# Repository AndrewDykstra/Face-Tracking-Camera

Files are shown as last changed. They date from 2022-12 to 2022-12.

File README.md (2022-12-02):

# Face-Tracking-Camera
This is a project I developed in my Engineering Honors class in high school which utilized an Arduino Rev3 and micro servos functioning as a pan-tilt to develop a face tracking camera.

I worked with the open source real-time computer vision library OpenCV for this project which is in C++, but I primarily coded in python. I developed the entire project at a cost of $45.76 which is significantly cheaper than alternative face tracking cameras on the market.

To physically encase the project, I had an iPhone box that I used an exacto knife to cut slits in to fit the wires through in order to connect to the webcam mounted on two micro servos. The two micro servos act as a pan-tilt so the camera can move accordingly when it indentifies a face to keep the face centered in the video. Inside of the iPhone box is the Arduino Rev3 and the breadboard that connects the Arduino to the micro servos. The last hole on the box is to connect the Arduino to my laptop where the code will be run to process the video feed from the webcam along with providing the Arduino with power.

This was one of my first larger projects where I properly documented my work in an engineering notebook and went through a proper design cycle of identifying the problem, researching solutions, identifying specifications, and prototyping. My engineering notebook is in the form of a pdf in this repository if you're interested in seeing more in depth data on my project along with regular progress updates.

The initial planning, designing, development, and any related information can be found in my engineering notebook. It also contains information on any bugs and difficulties along the way and I how I went about solving them.

Here are some pictures of what the final product looked like:

Outside look of the device
Inside look of the device
Facial recognition working

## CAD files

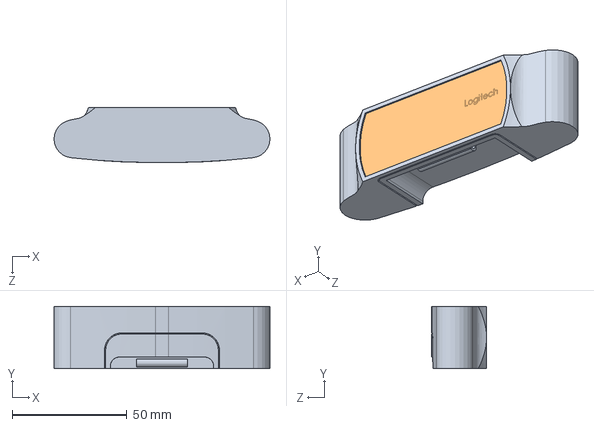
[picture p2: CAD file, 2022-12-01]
3D Model Parts and Assembly/LogitechC920Montaj.SLDASM
94.0 x 27.0 x 24.0 mm
Logitech_C920
Logitech_C920Glass

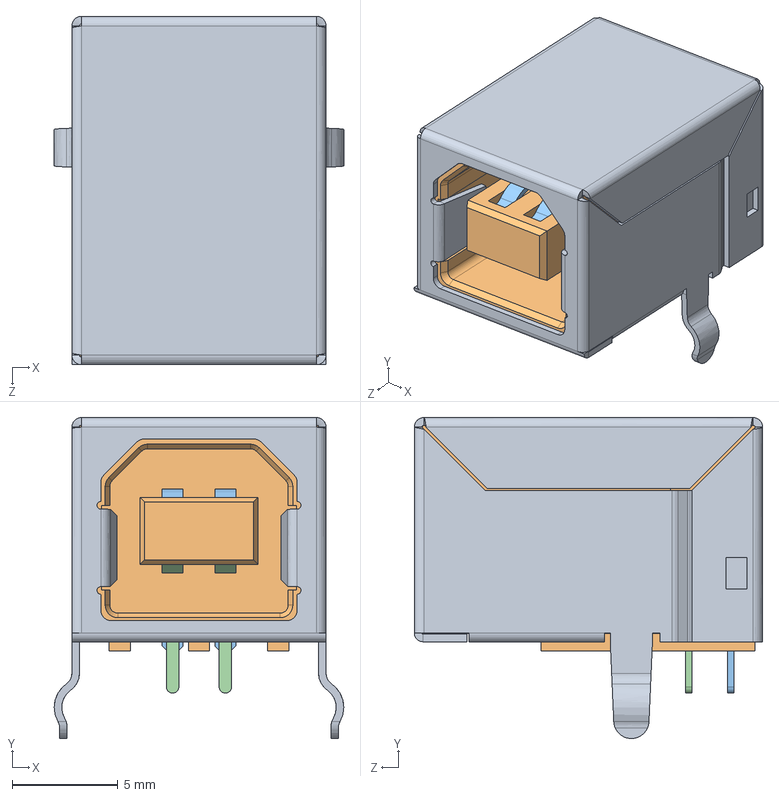
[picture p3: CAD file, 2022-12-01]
3D Model Parts and Assembly/ArduinoUno/USB type b.SLDPRT.SLDASM
13.7 x 15.2 x 16.5 mm
USB SHELL
USB core
usb top contact x 2
usb btm contact x 2

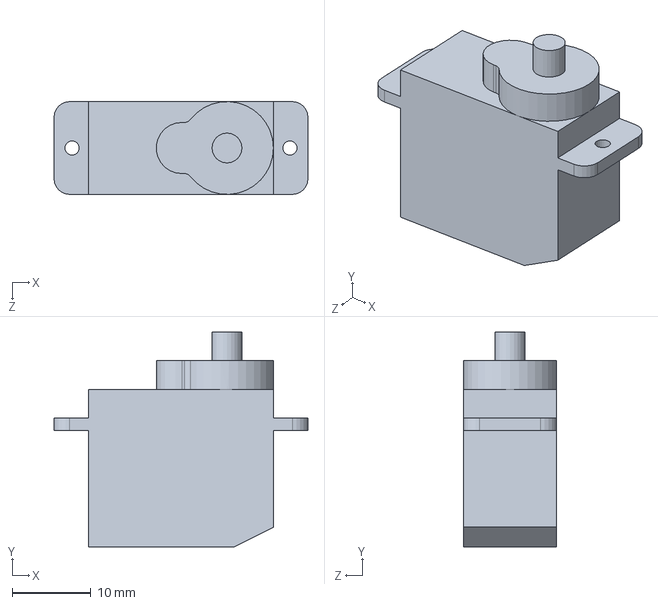
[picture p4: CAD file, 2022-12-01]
3D Model Parts and Assembly/servo_emax_9g_main_body.SLDPRT
32.3 x 27.3 x 11.8 mm

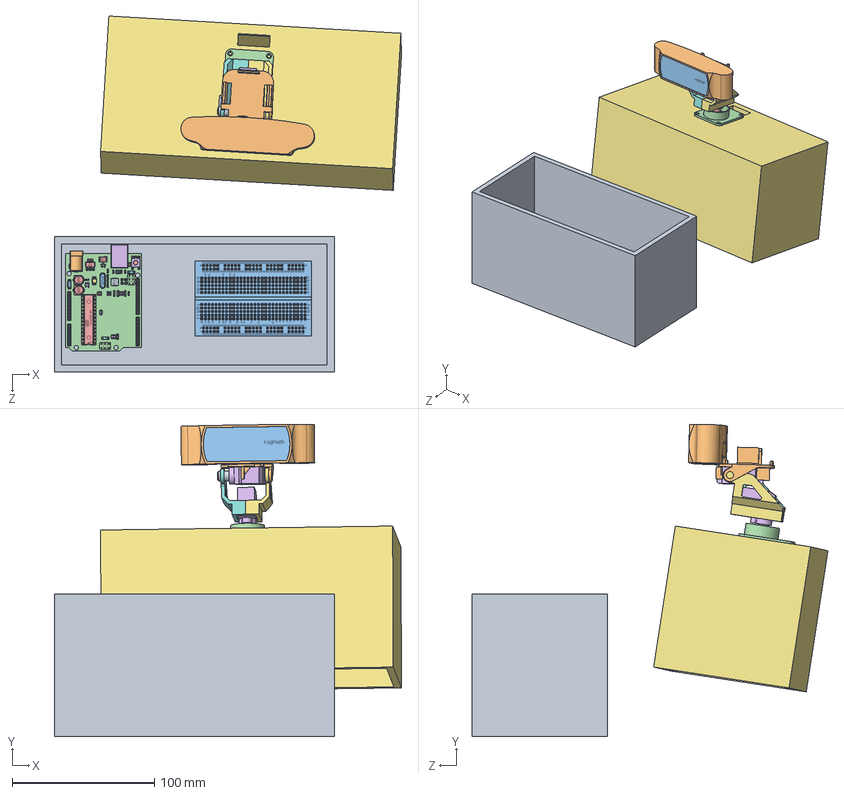
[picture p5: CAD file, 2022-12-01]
3D Model Parts and Assembly/FinalAssembly.SLDASM
244.0 x 219.7 x 250.3 mm
IphoneBox
Logitech_C920
Logitech_C920Glass
pantilt_1
servo_emax_9g_horn
servo_emax_9g_main_body x 2
pantilt_2_left
pantilt_2_right
servo_emax_9g_horn_2
pantilt_3
matrix
unoboard blue
47uf CAP Dcase x 2
USB SHELL
USB core
usb top contact x 2
usb btm contact x 2
power jack
crystal
2pin_header__02 x 6
nano - reg
led x 4
dip28
dip socket pin x 28
atmega16u2
8 PORT HEADER x 2
6 PORT HEADER
10 PORT HEADER
ATMEL328P
102 RESISTOR PACK x 2
103 RESISTOR PACK
220 RESISTOR PACK
16mhz crystal - measured
PADS001
603 cap on pad x 8
ssot3
mf-msmf050-2
lmv358
lp2985dgkr
cd1206 diode x 2
603 resistor
blm21
m7 diode
MLC0603 x 2
RESET CORE
RESET
IphonBoxLid

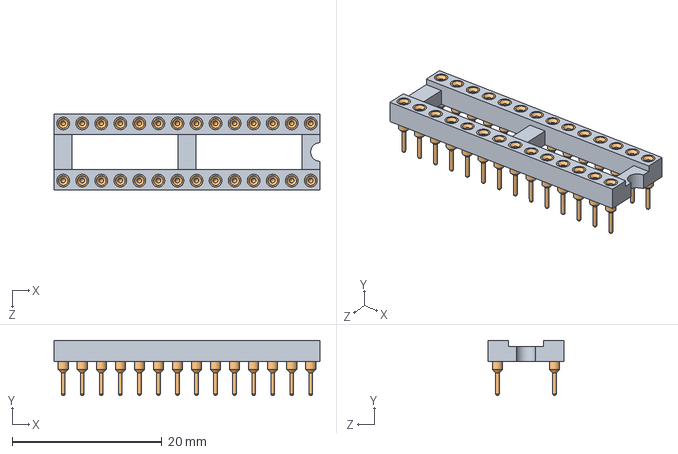
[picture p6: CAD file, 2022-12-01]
3D Model Parts and Assembly/ArduinoUno/dip28.SLDASM
35.5 x 7.37 x 10.1 mm
dip28
dip socket pin x 28

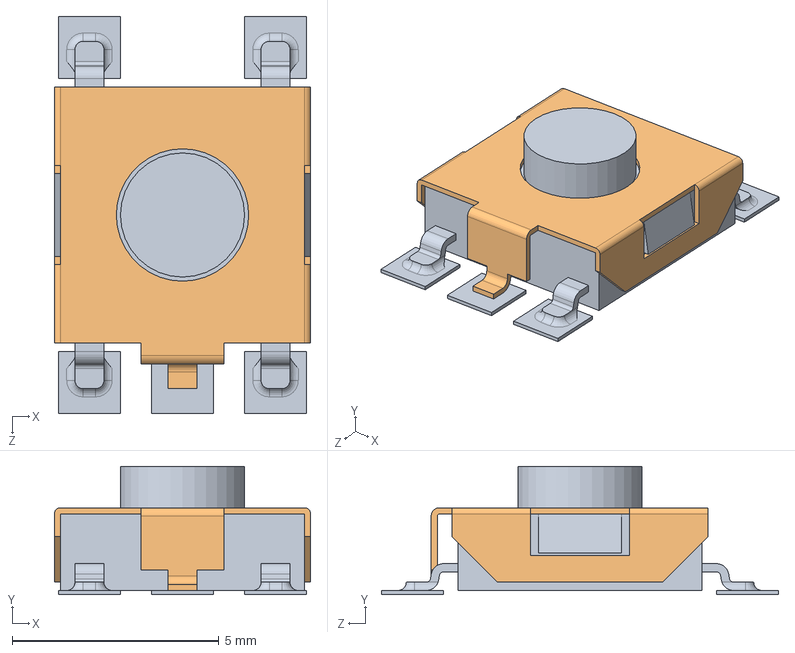
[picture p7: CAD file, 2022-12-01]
3D Model Parts and Assembly/ArduinoUno/RESET BUTTON.SLDASM
6.20 x 3.10 x 9.60 mm
RESET CORE
RESET

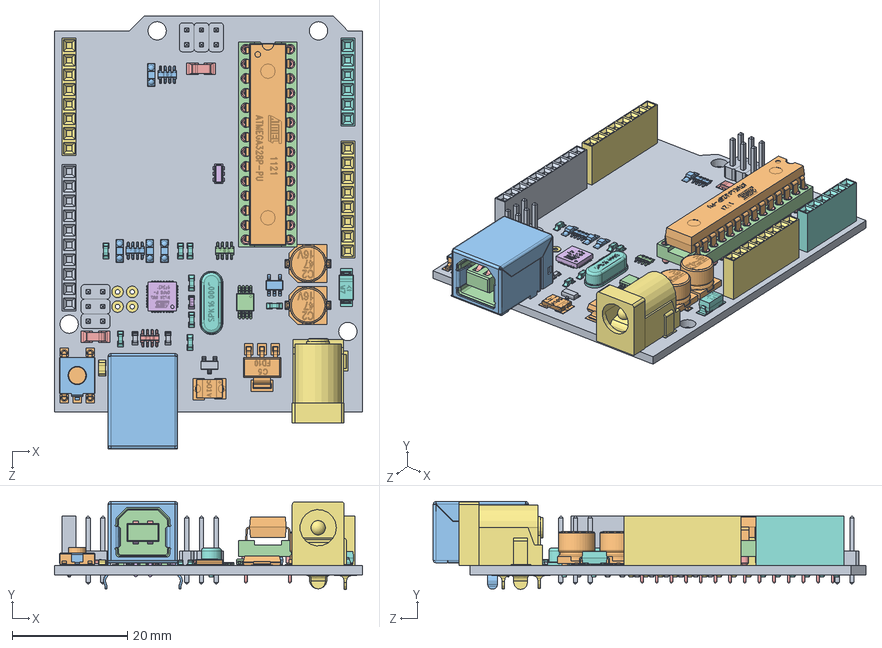
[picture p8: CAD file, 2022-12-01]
3D Model Parts and Assembly/ArduinoUno/arduino uno.SLDASM
53.3 x 15.2 x 74.9 mm
unoboard blue
47uf CAP Dcase x 2
USB SHELL
USB core
usb top contact x 2
usb btm contact x 2
power jack
crystal
2pin_header__02 x 6
nano - reg
led x 4
dip28
dip socket pin x 28
atmega16u2
8 PORT HEADER x 2
6 PORT HEADER
10 PORT HEADER
ATMEL328P
102 RESISTOR PACK x 2
103 RESISTOR PACK
220 RESISTOR PACK
16mhz crystal - measured
PADS001
603 cap on pad x 8
ssot3
mf-msmf050-2
lmv358
lp2985dgkr
cd1206 diode x 2
603 resistor
blm21
m7 diode
MLC0603 x 2
RESET CORE
RESET

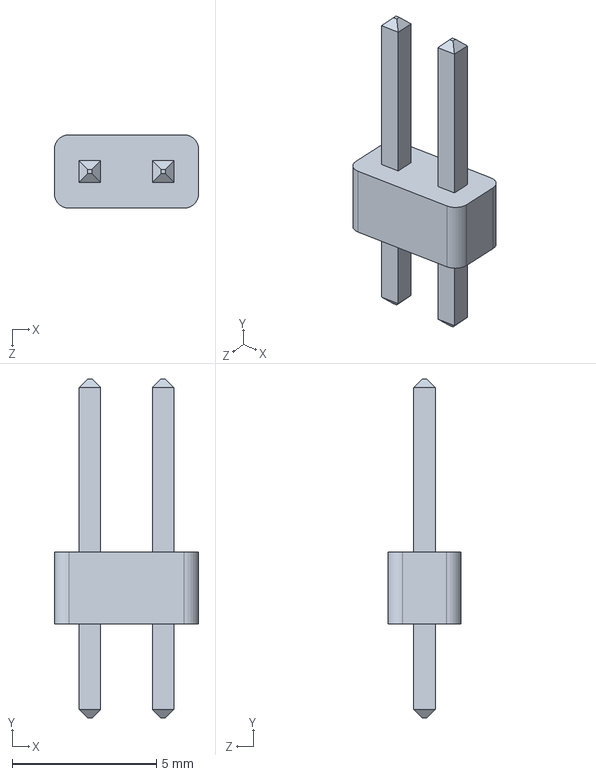
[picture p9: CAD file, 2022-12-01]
3D Model Parts and Assembly/ArduinoUno/2pin_header__02.sldprt
5.00 x 11.8 x 2.54 mm

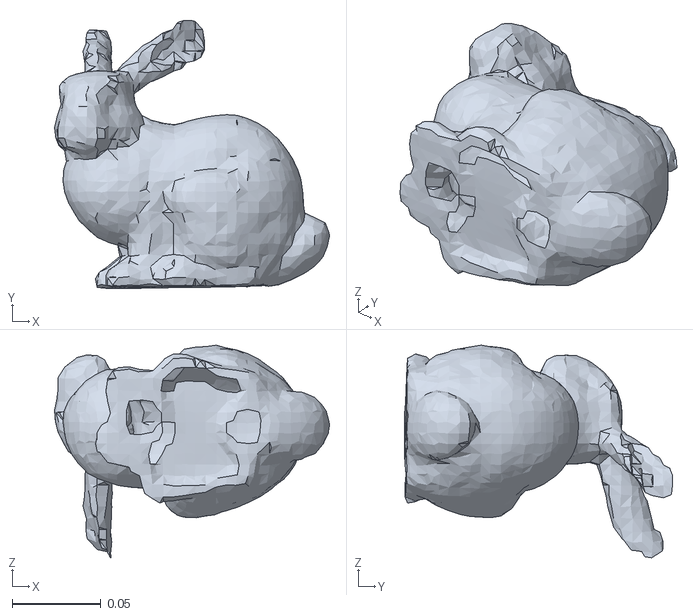
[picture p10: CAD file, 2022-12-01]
opencv/sources/samples/cpp/tutorial_code/viz/bunny.ply
0.155 x 0.151 x 0.12

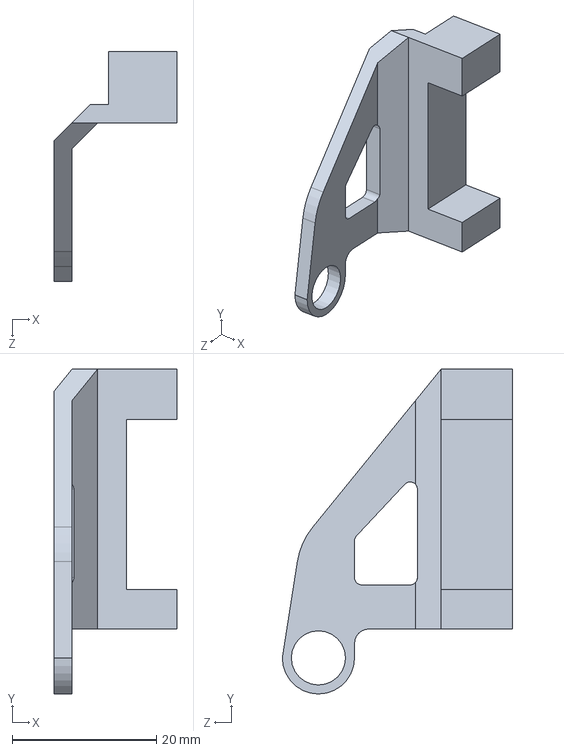
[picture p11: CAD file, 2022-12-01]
3D Model Parts and Assembly/pantilt_2_right.SLDPRT
17.0 x 45.0 x 31.9 mm

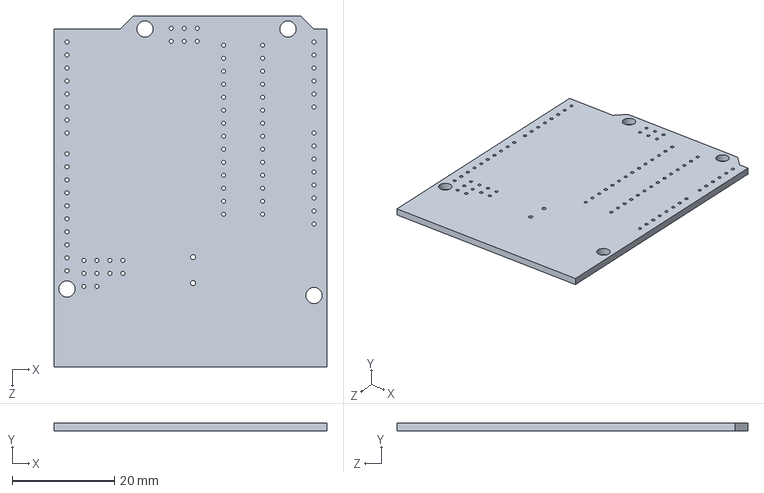
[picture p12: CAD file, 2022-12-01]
3D Model Parts and Assembly/ArduinoUno/unoboard blue.SLDPRT
53.3 x 1.65 x 68.6 mm

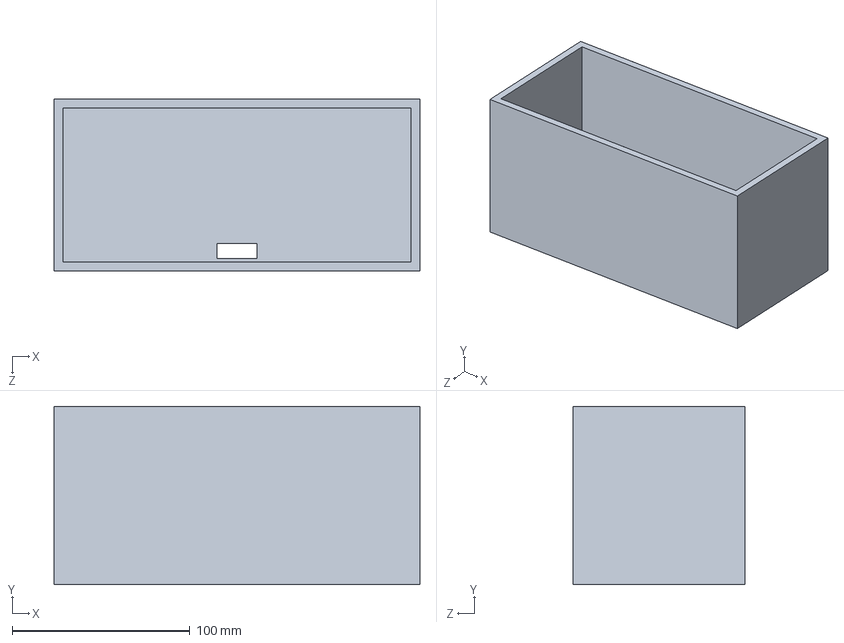
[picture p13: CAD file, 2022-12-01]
3D Model Parts and Assembly/IphonBoxLid.SLDPRT
205.7 x 100.3 x 96.5 mm

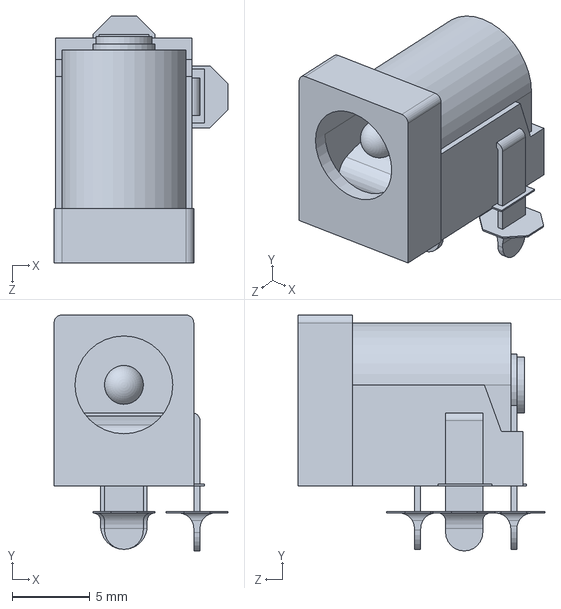
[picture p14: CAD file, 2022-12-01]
3D Model Parts and Assembly/ArduinoUno/power jack.SLDPRT
11.2 x 15.2 x 15.9 mm

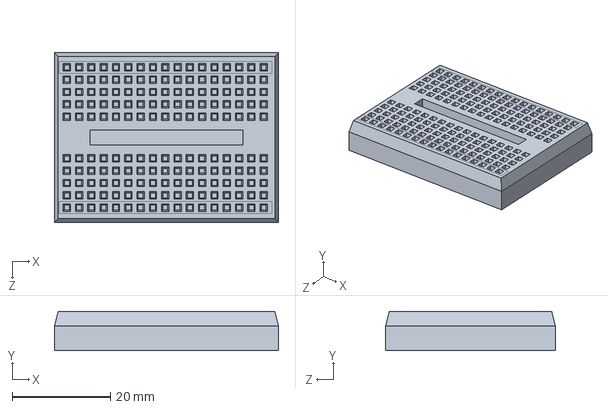
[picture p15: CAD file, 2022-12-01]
3D Model Parts and Assembly/Electronics_Prototyping_Breadboard_35x45x8_17x10holes.SLDPRT
45.5 x 8.00 x 34.5 mm

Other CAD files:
3D Model Parts and Assembly/ArduinoUno/blm21.SLDPRT
3D Model Parts and Assembly/ArduinoUno/atmega16u2.SLDPRT
3D Model Parts and Assembly/ArduinoUno/6 PORT HEADER.SLDPRT
3D Model Parts and Assembly/Logitech_C920.SLDPRT
3D Model Parts and Assembly/ArduinoUno/10 PORT HEADER.SLDPRT
3D Model Parts and Assembly/ArduinoUno/102 RESISTOR PACK.SLDPRT
3D Model Parts and Assembly/ArduinoUno/103 RESISTOR PACK.SLDPRT
3D Model Parts and Assembly/ArduinoUno/16mhz crystal - measured.SLDPRT
3D Model Parts and Assembly/ArduinoUno/220 RESISTOR PACK.SLDPRT
3D Model Parts and Assembly/ArduinoUno/47uf CAP Dcase.SLDPRT
3D Model Parts and Assembly/ArduinoUno/603 cap on pad.SLDPRT
3D Model Parts and Assembly/ArduinoUno/603 resistor.SLDPRT
3D Model Parts and Assembly/ArduinoUno/8 PORT HEADER.SLDPRT
3D Model Parts and Assembly/ArduinoUno/ATMEL328P.SLDPRT
3D Model Parts and Assembly/ArduinoUno/MLC0603.SLDPRT
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

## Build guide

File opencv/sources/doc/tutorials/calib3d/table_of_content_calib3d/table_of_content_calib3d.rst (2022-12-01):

.. _Table-Of-Content-Calib3D:

*calib3d* module. Camera calibration and 3D reconstruction
-----------------------------------------------------------

Although we got most of our images in a 2D format they do come from a 3D world. Here you will learn how to find out from the 2D images information about the 3D world.

.. include:: ../../definitions/tocDefinitions.rst

+
  .. tabularcolumns:: m{100pt} m{300pt}
  .. cssclass:: toctableopencv

  ===================== ==============================================
      **Title:** :ref:`CameraCalibrationSquareChessBoardTutorial`

                        *Compatibility:* > OpenCV 2.0

                        *Author:* |Author_VictorE|

                        You will use some chessboard images to calibrate your camera.

  ===================== ==============================================

  

+
  .. tabularcolumns:: m{100pt} m{300pt}
  .. cssclass:: toctableopencv

  ===================== ==============================================
     **Title:** :ref:`cameraCalibrationOpenCV`

                        *Compatibility:* > OpenCV 2.0

                        *Author:* |Author_BernatG|

                        Camera calibration by using either the chessboard, circle or the asymmetrical circle pattern. Get the images either from a camera attached, a video file or from an image collection.

  ===================== ==============================================

  

.. raw:: latex

   \pagebreak

.. toctree::
   :hidden:

   ../camera_calibration_square_chess/camera_calibration_square_chess
   ../camera_calibration/camera_calibration

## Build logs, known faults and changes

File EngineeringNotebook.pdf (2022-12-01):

Trimester 2 Project Thursday, December 5, 2019 8:25 AM

12/5/19 - Brainstorming Ideas and Recognizing the Problems - Step 1 Understand

- Problem - Can't take photos with everyone in the photo because someone needs to align the camera and not always somewhere to prop the camera
- Solution - Automatic photographer
- Uses facial recognition to align
- Multiple modes • On
- Off • Timer(Infinitely many times you can set) • Have a button to raise or lower time • OLED board to display delay
- Items needed most likely
- Arduino (Rev3?) • OLED Board
- Breadboard
- Wires • Servos/Micro servos
- Camera/webcam
- Preferably capable of taking images as well • If time allows for it • Add a microphone option, if decibel threshold is reached

= snap photo

1/5/20 Researching Past Solutions – Step 2 Explore
- Some cameras come with auto centring capabilities
- All very expensive
- Over $300
- Some not very effective
- Large mount often necessary
- Not as portable

1/17/20 - Researching the Pan Tilt – Step 2 Explore
- 2 servos necessary
- Attached to some sort of base/rack
- One facing towards the ground
- One attached to the base of the first servo going perpendicular
- Micro servos most likely possible
- Advantages of using micro servo
- Cheaper
- Good for budget • Smaller • Could be advantageous for portability
- Disadvantages of using micro vs normal size servo
- Not as strong
- Predicting it will be strong enough for a camera, but there's a chance a micro servo won't be • Shorter servo

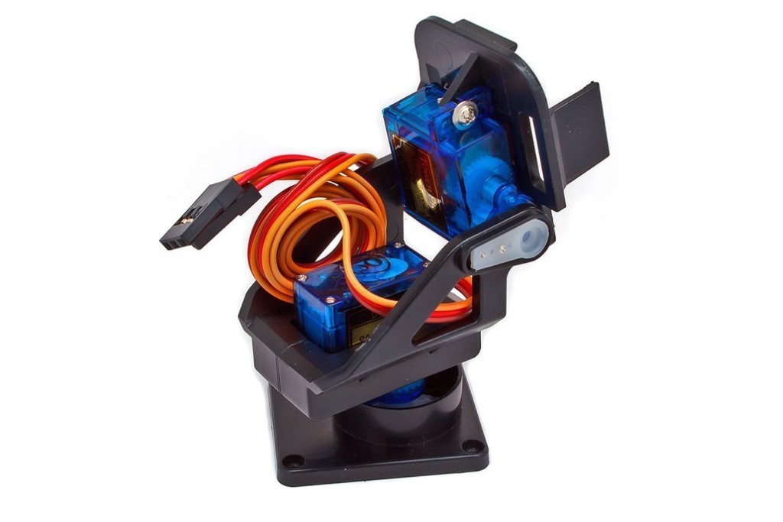
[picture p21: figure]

Previously made pan tilt using 2 servos

1/23/20 - Researching different Arduinos – Step 2 Explore Arduino Rev 3

- Operating Voltage: 5v
- Input Voltage recommended: 7-12V
- Input Voltage limit: 6-20V
- Digital I/O pins: 14
- PWM Digital I/O pins: 6
- Analog input pins: 6
- DC Current per I/O pin: 20mA
- DC Current for 3.3V pin: 50mA
- Flash memory: 32kb

Arduino Mega 2560 Rev 3
- Operating Voltage: 5v
- Input Voltage recommended: 7-12V
- Input Voltage limit: 6-20V
- Digital I/O pins: 54
- PWM Digital I/O pins: 0
- Analog input pins: 16
- DC Current per I/O pin: 20mA
- DC Current for 3.3V pin: 50mA
- Flash memory: 256kb

Pros of Mega vs Normal Rev 3
- More pins
- More pins most likely won't be necessary
- More memory
OneNote | https://usc-onenote.officeapps.live.com/o/onenoteframe.aspx?ui=en%...
1 of 6 | 11/30/2022, 11:10 PM

- Could be useful depending on size of facial recognition program

Cons of Mega vs Normal Rev 3
- Much more expensive
- Normal rev 3 $18 vs $32.75 Mega rev 3
- Takes up over half of the budget which isn't very realistic to buy all the other components with the remaining $17.25
1/24/20 - Researching Measurements – Step 3 Define Components | Length | Width | Weight Arduino Rev 3 | 68.6 mm | 53.4 mm | 25 g Possible Camera | n/a | n/a | n/a
Servo | 29mm | n/a | n/a Micro servo | 38mm | n/a | n/a Possible Cameras: 1. https://www.amazon.com/Cimkiz-Webcam-Built-Computer-Black/dp

/B07GVF4M25/ref=sr_1_37?qid=1579889972& refinements=p_36%3A1253503011&s=pc&sr=1-37

### 2. https://www.amazon.com/docooler-Megapixel-Camera-Desktop-

Computer/dp/B00OB88D2Y/ref=pd_cp_147_4 /145-8739310-6714348?_encoding=UTF8&pd_rd_i=B00OB88D2Y& pd_rd_r=5e655b80-2485-43a1-a1a9-6cb1d3925ca8&pd_rd_w=z4fKC& pd_rd_wg=5Ff5x&pf_rd_p=592dc715-8438-4207-b7fa-4c7afdeb6112& pf_rd_r=ABCV7NZVH8NS86ETJKQG&psc=1& refRID=ABCV7NZVH8NS86ETJKQG
-Comes with built in microphone as well

1/28/20 Necessary Prototype of 3d Printed Component – Step 4 Ideate
- Problems ○ Not enough work finished to determine the dimensions
- Specific shape to hold components once all together
- Position of components are unknown currently
- Current design
- A simple 80mm by 60mm rectangle that has 4mm thick offset walls that is large enough to hold an Arduino rev 3

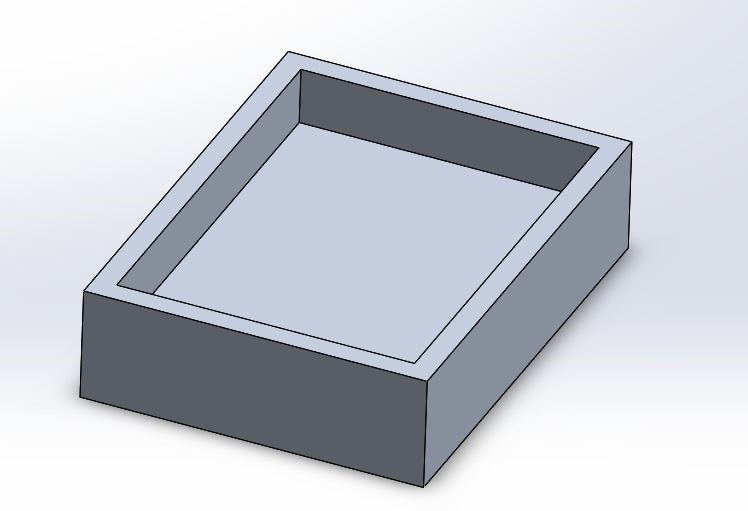
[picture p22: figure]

80mmx60mmx10mm Rectangle with 4mmx60mmx10mm walls

2/3/20 Components and Budget – Step 3 Define Part | Purpose | Price Arduino | Main computer controlling the servos | $18.00
2 MG90s' | Servos to rotate the camera upon a pan tilt | $6.00
Wires | Necessary for the circuit | N/A
Breadboard | Connect components (preferred to not have a somewhat other projects) permanent project because I will be reusing the parts for | Unknown Currently USB cable
type A/B | Connects the Arduino to the computer/laptop which is running the facial recognition code | $3.95
Webcam | Necessary to capture images/video for the code to process and track a face (Deciding on camera still) | N/A
USB Hub | Necessary to plug in a USB webcam and the USB type A/B cable from the Arduino to the laptop at the same time(My laptop only has 1 USB port which is a limiting factor) | N/A
Current Known Total | All Known prices currently to help estimate how much I have left to spend on necessary components | $27.95
Rough Total Estimate | Must be less or equal to $50 | ~$45

2/7/20 Developing Circuit Idea – Step 4 Ideate

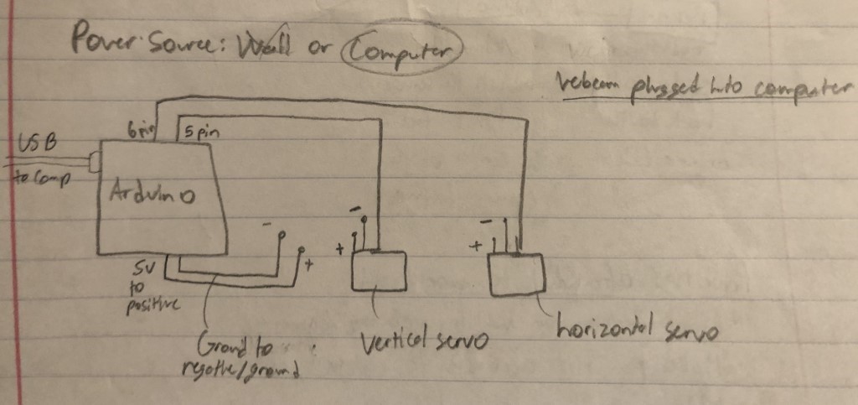
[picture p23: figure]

2/9/20 Drawn up Circuit Idea – Step 4 Ideate

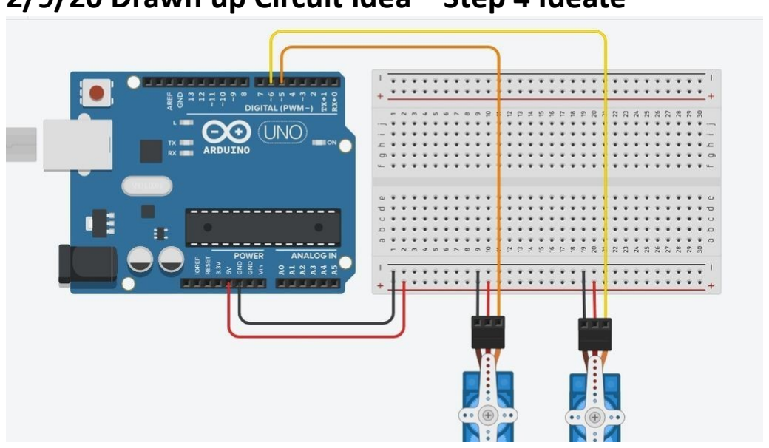
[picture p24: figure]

2 of 6 | 11/30/2022, 11:10 PM

2/10/20 Testing Servos – Step 5 Prototype
Tutorial Used for Project: https://create.arduino.cc/projecthub/WolfxPac/face-tracking-using-arduino-b35b6b
Testing to see if the servos work properly
- Should be capable of 180 degree rotation
- Made simple code with Arduino communicating with Tera Term
- Through Serial
- Code is in "testingservos" folder
- Tera Term is a third part program allowing Serial communication with an Arduino and keyboard interactions
- Singular Servo plugged into 5 ping, 5 volt, and grounded
- Tested each servo individually and they both worked

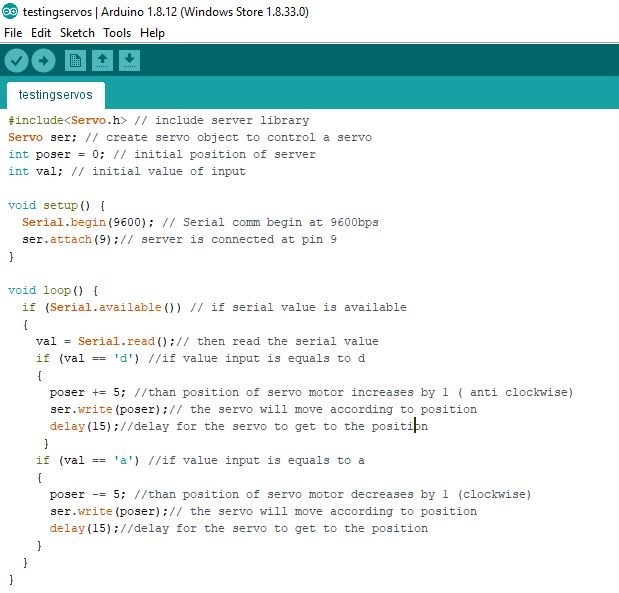
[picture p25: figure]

2/12/20 Testing the Circuit Model – Step 5 Prototype

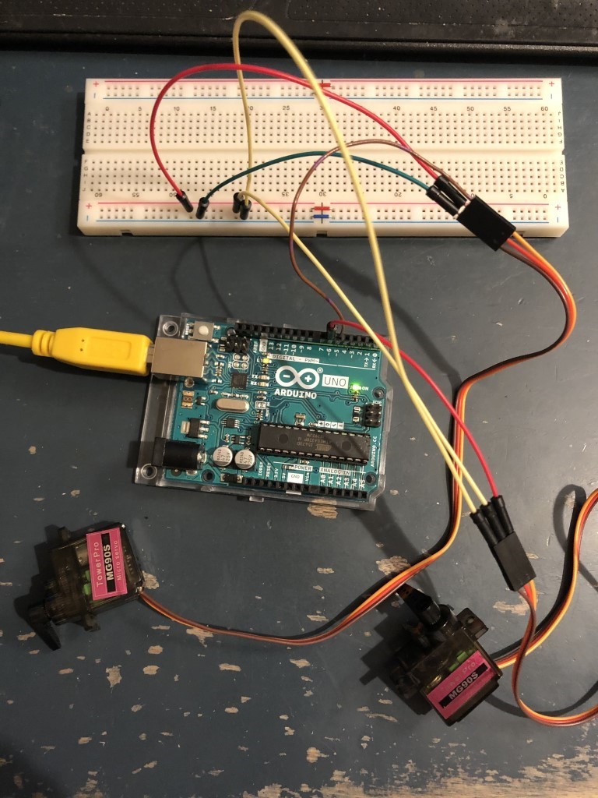
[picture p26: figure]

2/15/20 Planning Facial Recognition and Tracking – Step 4 Ideate
- Planning on using OpenCV – Python for facial recognition
- Code that is capable of identifying a face based off of embeddings, cascades, and nodes
- Haar Cascade Created by Rainer Lienhart • Facial detection
- Make python code to make a display/window that shows the webcam input and the coordinates being output to the Arduino
- Also include a centerpoint to check for alignment of a face once tracking ○ Send coordinates to serial to send to Arduino • Arduino code then take the coordinates from Serial and move the servos in the pan tilt accordingly to align the

detected face in the middle of the video capture

2/17/20 Starting Code – Step 6 Choose
- Using OpenCV and Haar Cascade approach
- First downloaded OpenCV, PySerial, Numpy, and Haar Cascade
- Pip installed OpenCV, Numpy, and Serial through cmd
- Started coding python display to display Haar Cascade output
- Made the basic display window with a center point and + sign to split the screen into 4 quadrants
- 500 by 500 pixel window

2/22/20 Finished Python Code for Display and Arduino Code– Step 7 Refine and Step 9 Implement
- Finished the Python code by adding constant feed of what the Haar Cascade is outputting and sending to the Arduino via serial
- Made all of the Arduino code today
- Servos will start at 90 degrees
- React to whatever coordinates are sent from the Python code through serial
- Max and min degrees set
- Min: 70 degrees for horizontal servo
- Min: 95 degrees for vertical servo
3 of 6 | 11/30/2022, 11:10 PM

- Max: 179 degrees for vertical and horizontal servos
- Facial recognition works and outputs values fine, but servos won't move ○ Checked servos are still working with "testingservos.ino" and

they both worked fine

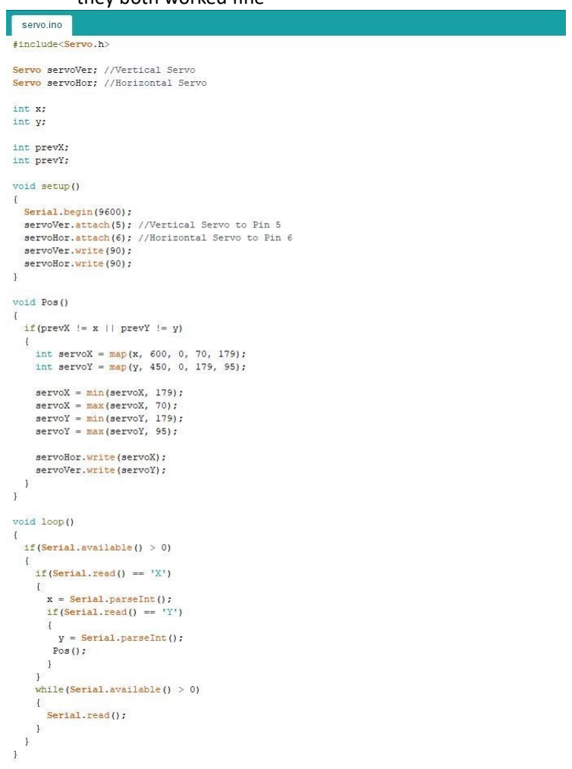
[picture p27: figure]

2/25/20 Problems with Servos – Step 7 Refine
- data = "X{0:d}Y{1:d}Z".format(xx, yy)
- Have to change d representing a double type to f for a float, code originally worked in Python 2.7.4, but isn't working in 3.8.2
- Arduino.write(data.encode())
- Both lines are causing a problem with communicating with Arduino ○ This line of code is preventing any signal through serial to get to

the Arduino resulting in the servos not working
- Code had previously worked on an older version of Python and OpenCV on my desktop (version 2.7.4 of Python)

2/26 Debugging Code – Step 7 Refine
- First going to attempt downloading an older version of Python and OpenCV to test current code with
- Downloaded Python 2.7 and OpenCV 2.1 on laptop
- Pip cut off support for Python 2.7 if you don't already have the old pip installed
- Must adapt the current code, can't use the old version
- Ran basic logic code to check if there is any signal going between the serial and reaching the Arduino
- Current code there is a flashing light on the Arduino as if it is receiving information

2/27/20 Debugging and Pan Tilt Kit – Step 7 Refine
- Ran several steps of logic testing
- Tested if python code was outputting values • Passed ○ Tested if circuit was getting power • Passed ○ Tested servos to see if they work independently • Passed ○ Tested Pyserial connection to Arduino
- Passed Root of problem still unknown, but ordered kit for pan tilt. Decided to

buy a pan tilt kit after reconsidering the amount of time remaining and little progress on finding the root of the error in the code.

2/30/20 Finished Debugging and Testing – Step 10 Test
Error was a very simple fix, but took a long time to pin point. The Arduino code was attempting to parse an int while the output of the python code being sent through pyserial was a float so it was not receiving an integer it could interpret.

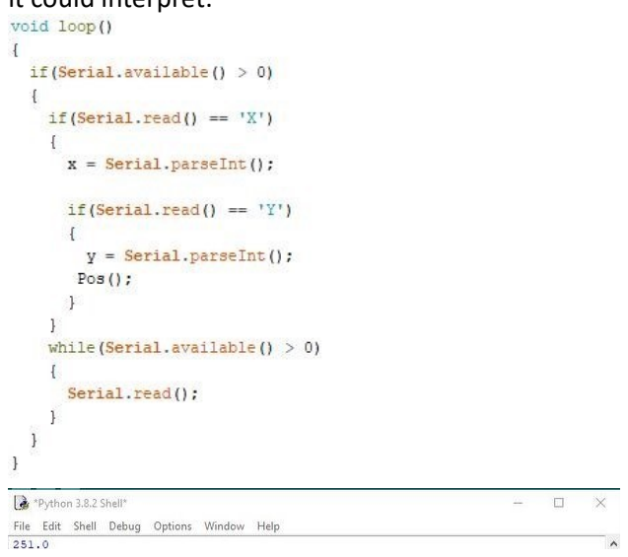
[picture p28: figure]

4 of 6 | 11/30/2022, 11:10 PM

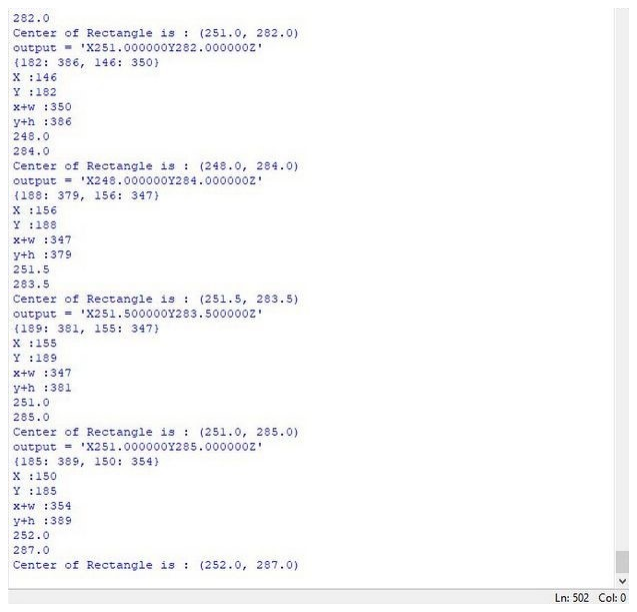
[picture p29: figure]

2/31/20 Found a box to fit the project in – Step 6 Choose Planning on using an old iPhone box
Length: About 6 ¾ Inches Width: About 3 ¾ inches Capable of holding the Arduino and the bread board

3/1/20 Pan Tilt Arrived and Assembled – Step 9 Implement Pan Tilt Assembly
- Took out all of the parts
- No instructions were included and the servo pins did not fit...
- I cut the servo pins to fit accordingly
- Used a hot glue gun to attach the horizontal servo to the base
- Cut the top servo's pin to fit into the notch because the pin did not fit and I had no pin that could fit
- Through trial and error, I found the correct screws provided to fasten the remaining parts together
- Filed down the camera on the bottom to get a flat surface to sit on the pan tilt

3/3/20 Finalizing Bill of Materials – Step 11 Reflect
Note: bought some sticky 3M squares to attach some parts Part | Purpose | Price Arduino | Main computer controlling the servos | $18.00
2 MG90s' | Servos to rotate the camera upon a pan tilt | $6.00
Wires | Necessary for the circuit | $0.49
Breadboard | Connect components (preferred to not have a somewhat permanent project because I will be reusing the parts for other projects) | $2 USB cable
type A/B | Connects the Arduino to the computer/laptop which is running the facial recognition code | $3.95 Webcam
HPKQ245AA Web Cam | Necessary to capture images/video for the code to process and track a face | $10.00
Lightning to USB adapter | Necessary due to my laptop only having 1 USB port when I need access to two | $4.00 Mounting
Squares | Also referred to as sticky squares, needed to attach multiple parts on my widget | $1.14 Hot Glue
stick | Needed to assemble pan tilt due to servo pins not fitting | $.18
Rough Total Estimate | Must be less or equal to $50 | $45.76

There are screenshots of the prices in google drive

3/4/20 Finishing Project – Step 10 Test and Step 11 Reflect
Assembly
- Used 4 of the squares to stick the Arduino to the bottom of the iPhone box • Then peeled off the back of the sticky paper on the breadboard and

stuck it to the iPhone case next to the Arduino
- Then used an exacto knife to cut out a notch in the iPhone case for the USB type A/B to plug into the Arduino through
- Used two more of the sticky squares to attach the pan tilt to the top of the iPhone case • Cut another hole on the lid of the iPhone box to feed the servo wires

through to connect to the circuit
- Used another sticky square to attach the webcam to the pan tilt (7 used in total)
- Rewired the circuit and tested out the widget

Testing
- Camera was originally very twitchy so I added a sleep time on the update feed
- Added a sleep timer of 0.1 of a second on the python code so it wouldn't update as fast
- I had to recode some of the adjustments and min and max angles of the camera according to the field of vision of the camera
- The webcam has a FOV of about 30 degrees so adjusted the max, min, and adjustments to center accordingly What I would do in the future • I would spend more time tweaking the facial recognition to make it

more accurate and not lock onto random objects falsely being identified as a face • I would also make the camera capable of identifying multiple faces

5 of 6 | 11/30/2022, 11:10 PM

and having a priority feature so it would prioritize the closest face or possibly have a mod to center between all of the faces

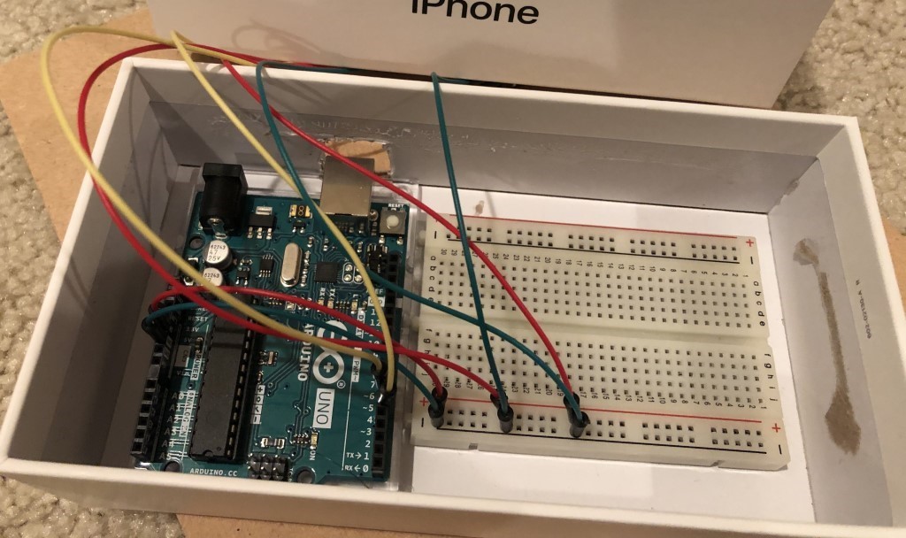
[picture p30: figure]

Photo of the inside and circuity of the widget

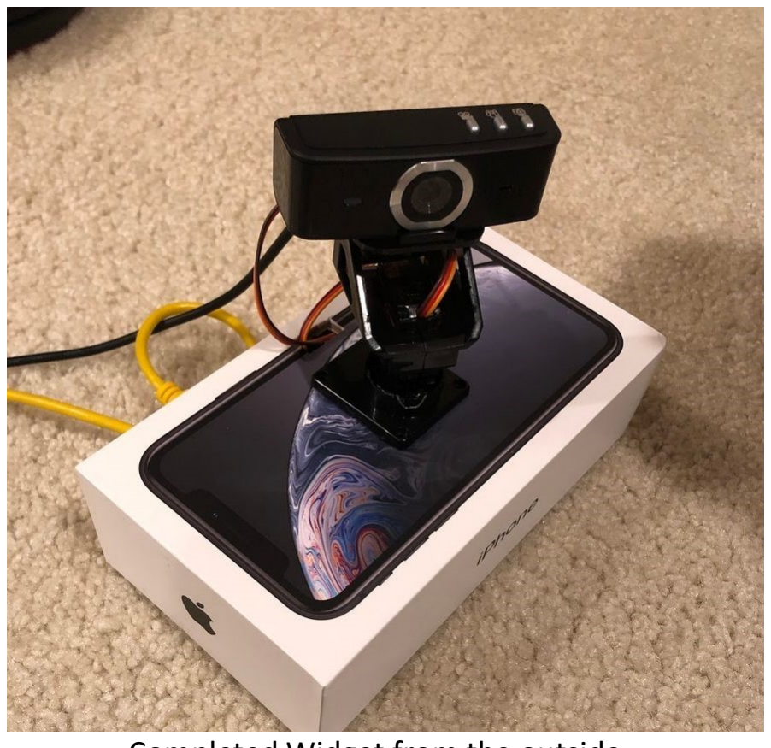
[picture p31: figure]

Completed Widget from the outside

6 of 6 | 11/30/2022, 11:10 PM

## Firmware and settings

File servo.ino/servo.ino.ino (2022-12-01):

#include<Servo.h>

Servo servoVer; //Vertical Servo
Servo servoHor; //Horizontal Servo

int x;
int y;

int prevX;
int prevY;
int servoX = 90;
int servoY = 90;

void setup()
{
  Serial.begin(9600);
  servoVer.attach(5); //Attach Vertical Servo to Pin 5
  servoHor.attach(6); //Attach Horizontal Servo to Pin 6
  servoVer.write(servoY);
  servoHor.write(servoX);
}

void Pos()
{
  if(prevX != x || prevY != y)
  {
    //tune this range to generate map
    int deltaX = map(x, 500, 0, -15, 15); 
    //tune this range to generate map
    int deltaY = map(y, 0, 450, 15, -15);

    servoX += deltaX;
    servoY += deltaY;

    servoX = min(servoX, 160);
    servoX = max(servoX, 20);
    servoY = min(servoY, 150);
    servoY = max(servoY, 90);
    
    servoHor.write(servoX);
    servoVer.write(servoY);

    prevX = x;
    prevY = y;
  }
}

void loop()
{
  if(Serial.available() > 0)
  {
    if(Serial.read() == 'X')
    {
      x = Serial.parseInt();
      if(Serial.read() == 'Y')
      {
        y = Serial.parseInt();
       Pos();
      }
    }
    while(Serial.available() > 0)
    {
      Serial.read();
    }
  }
}

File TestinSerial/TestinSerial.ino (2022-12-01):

char serialData;
int pin=10;

void setup() {
  pinMode(pin, OUTPUT);
  Serial.begin(9600);
}

void loop() {
  if(Serial.available() > 0)
    serialData = Serial.read();
    Serial.print(serialData);

    if(serialData == '1'){
      digitalWrite(pin, HIGH);
    } else
    if(serialData == '0'){
      digitalWrite(pin, LOW);
    }
}
